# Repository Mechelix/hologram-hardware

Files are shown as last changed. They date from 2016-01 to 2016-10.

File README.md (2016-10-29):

# Hologram Dash and Dash Pro Hardware Repo

Welcome to Hologram
We hope you enjoy using our hardware

This is the repo for the Dash and Dash Pro

You can find everything you need to at
https://hologram.io/start

You can find the user manual here:
https://hologram.io/docs/hardware/hologram-dash/

There is also a great index of documentation here:
https://hologram.io/docs/

You can find our forums here. We really want to hear about your projects!
https://community.hologram.io/

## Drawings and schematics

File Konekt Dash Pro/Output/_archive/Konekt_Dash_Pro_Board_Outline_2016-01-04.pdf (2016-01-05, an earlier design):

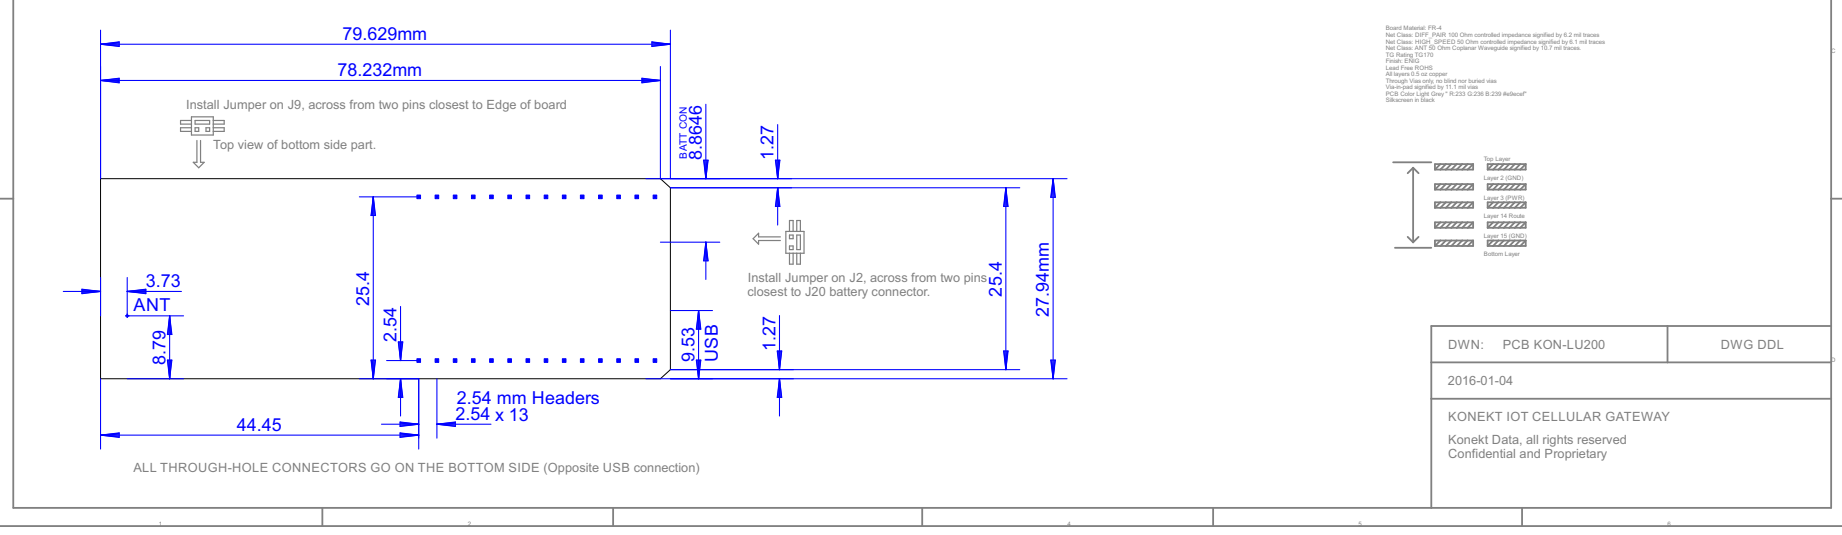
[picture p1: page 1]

Board Material: FR-4 Net Class: DIFF_PAIR 100 Ohm controlled impedance signified by 6.2 mil traces Net Class: HIGH_SPEED 50 Ohm controlled impedance signified by 6.1 mil traces Net Class: ANT 50 Ohm Coplanar Waveguide signified by 10.7 mil traces. TG Rating TG170 Finish: ENIG

Lead Free ROHS
All layers 0.5 oz copper Through Vias only, no blind nor buried vias Via-in-pad signified by 11.1 mil vias PCB Color Light Grey " R:233 G:236 B:239 #e9ecef" Silkscreen in black

Install Jumper on J9, across from two pins closest to Edge of board Top view of bottom side part.

Top Layer Layer 2 (GND) Layer 3 (PWR) Layer 14 Route

Layer 15 (GND) Bottom Layer

Install Jumper on J2, across from two pins
closest to J20 battery connector.

DWN: 2016-01-04 KONEKT IOT CELLULAR GATEWAY

Konekt Data, all rights reserved Confidential and Proprietary

ALL THROUGH-HOLE CONNECTORS GO ON THE BOTTOM SIDE (Opposite USB connection)

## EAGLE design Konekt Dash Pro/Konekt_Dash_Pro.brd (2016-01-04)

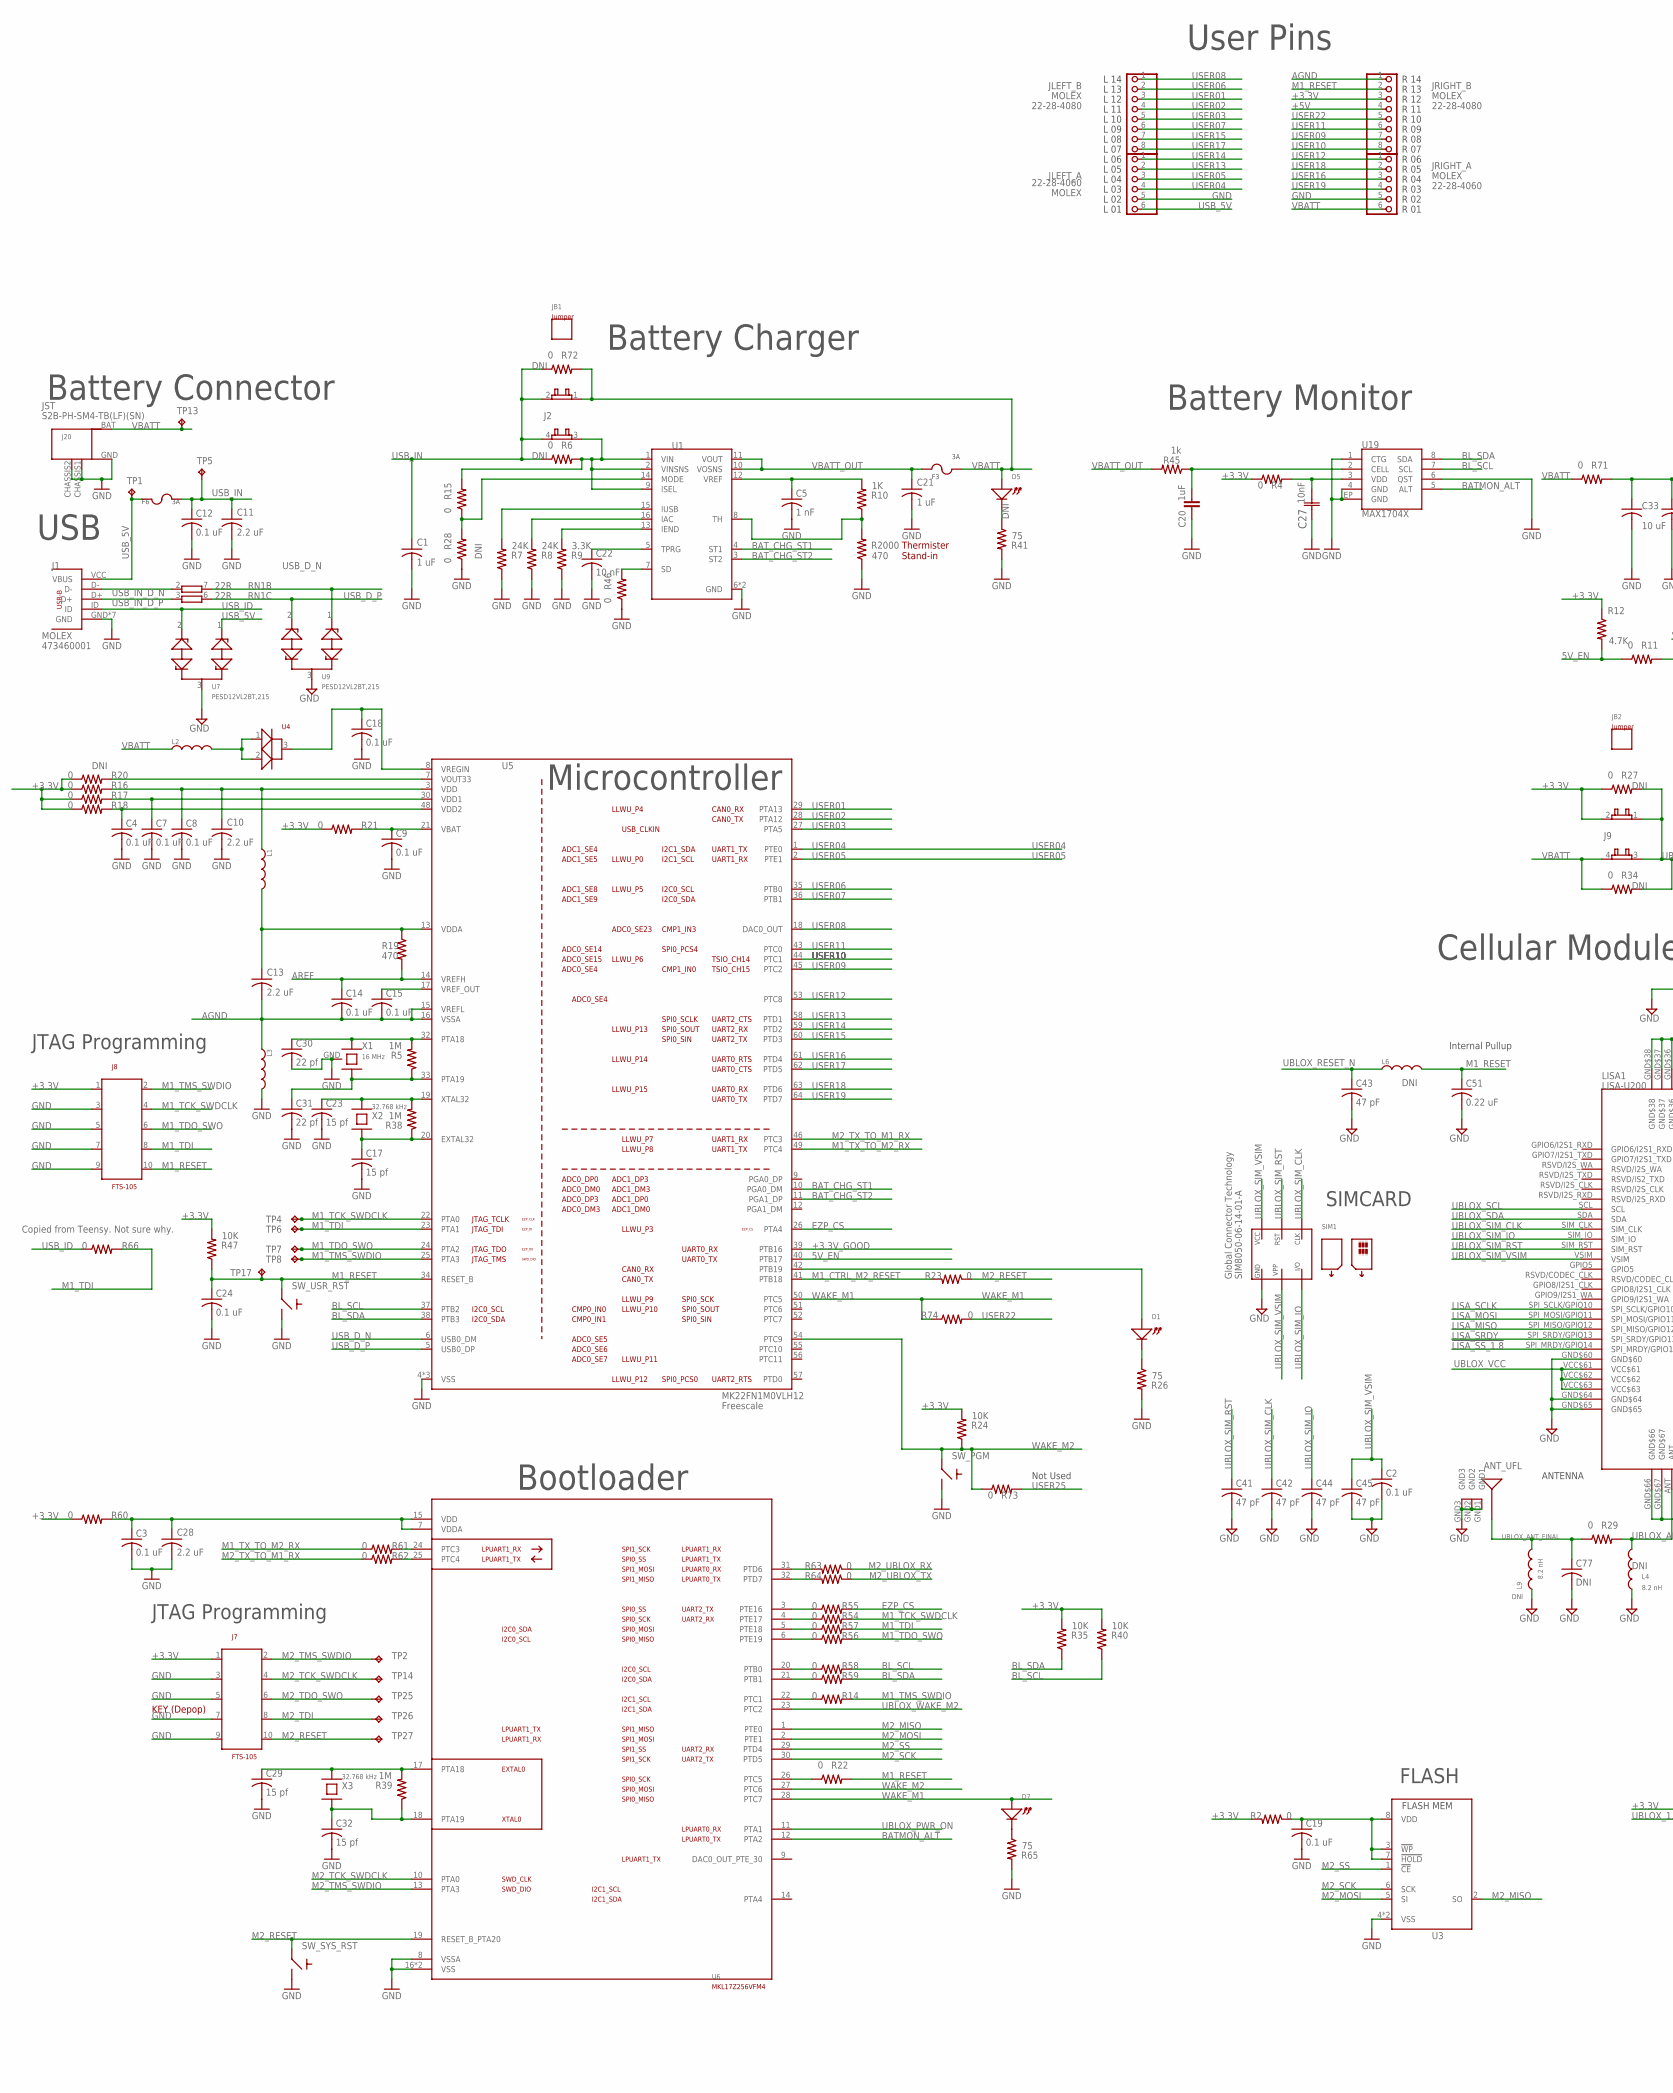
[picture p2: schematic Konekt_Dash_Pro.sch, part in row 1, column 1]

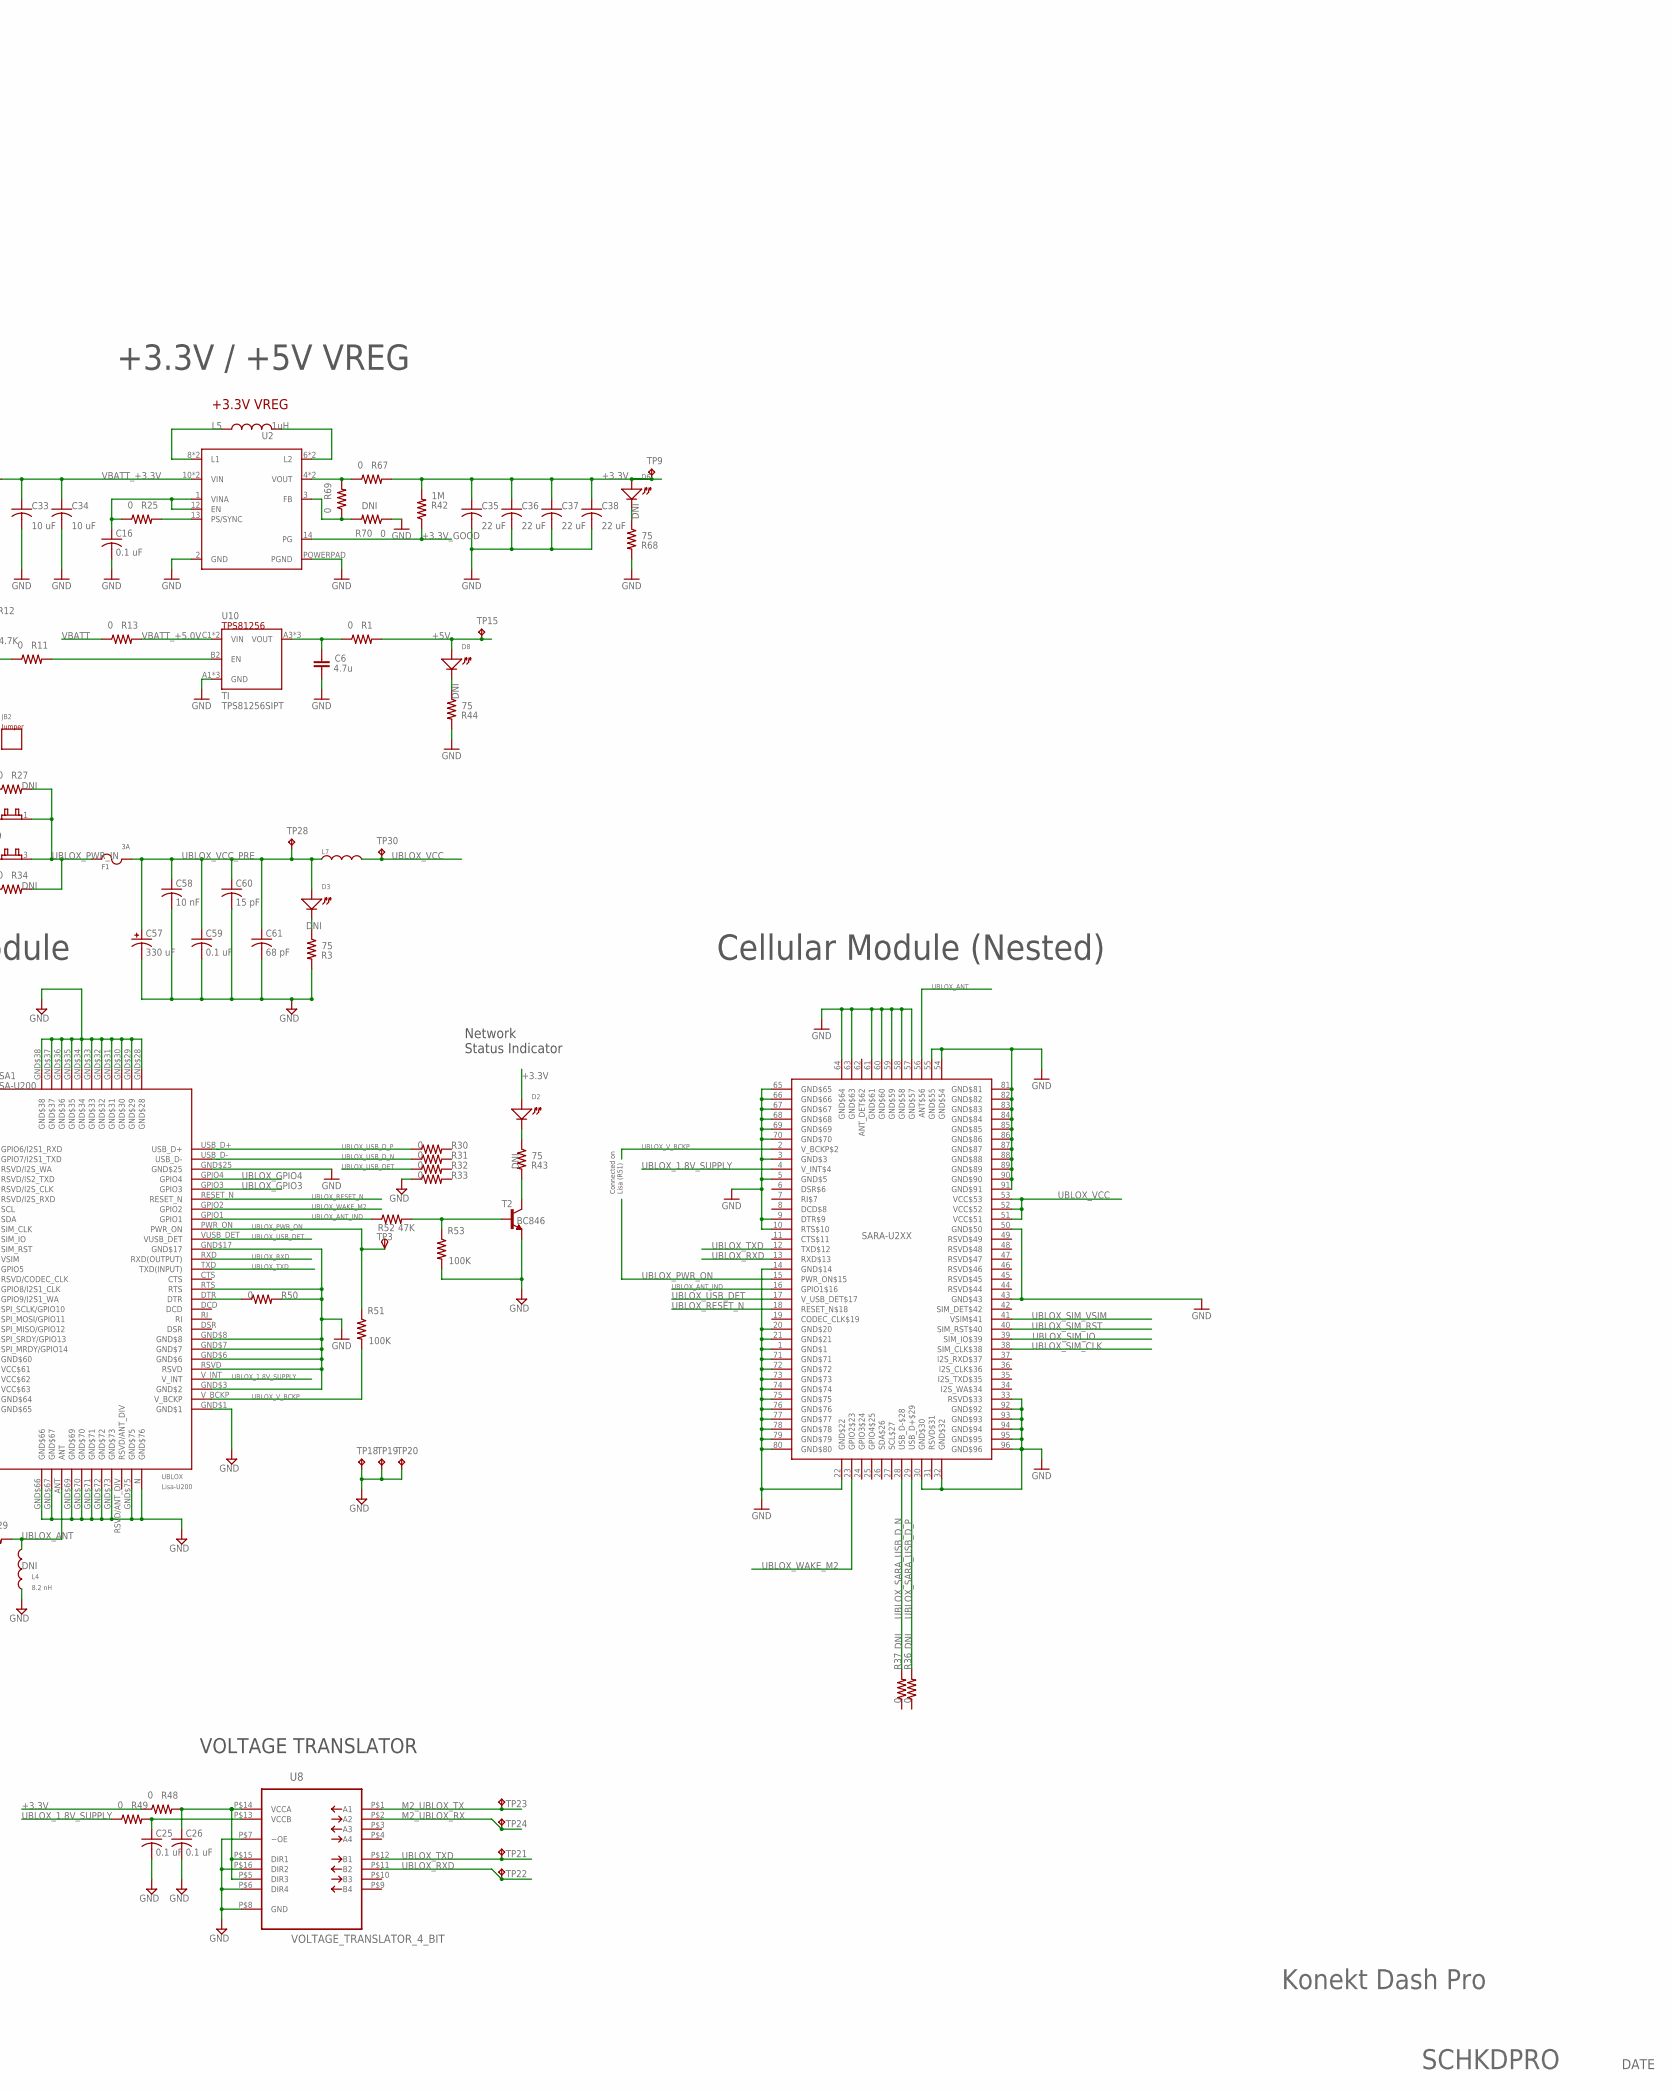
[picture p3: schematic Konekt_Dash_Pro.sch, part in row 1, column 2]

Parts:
ANT_UFL: ANT-A-1JB; UFL; MPN A-1JB
C1, C21: 1 uF; C0603; MPN GRM188R71C105KA12D
C2, C3, C4, C7, C8, C9, C14, C15, C18, C19, C24, C25, C26: 0.1 uF; C0402; MPN GRM155R61C104KA88D
C5: 1 nF; C0402; MPN GRM319R71H102KA01D
C6: 4.7u; C0603-ROUND; MPN GRM188R61C475KAAJD
C10, C11, C13, C28: 2.2 uF; C0603; MPN CL10A225MQ8NNNC
C12, C16, C59: 0.1 uF; C0603; MPN 0603YC104KAT2A
C17, C23, C29, C32: 15 pf; C0402; MPN 04025A150JAT2A
C20: 1uF; 0402-CAP; TOLERANCE 10%; VOLTAGE 50V; MPN 04026D105KAT2A
C22, C58: 10 nF; C0402; MPN GRM155R71C103KA01D
C27: 10nF; CAPC1005X60N
C30, C31: 22 pf; C0402; MPN 04025A220JAT2A
C33, C34: 10 uF; C0603; MPN GRM188R60J106ME84D
C35, C36, C37, C38: 22 uF; C0603; MPN GRM188R60J226MEA0D
C41, C42, C43, C44, C45: 47 pF; C0402; MPN 04025A470JAT2A
C51: 0.22 uF; C0603; MPN 0603YC224KAT2A
C57: 330 uF; CAP_SMD_SIZE_D; MPN T520D337M006ATE045
C60: 15 pF; C0402; MPN NMC0402NPO150J50TRPF
C61: 68 pF; C0402; MPN GRM1555C1H680JA01D
C77: DNI; C0402; MPN DNI
D1, D2, D3, D5, D6, D7, D8: LED_0402_VLMW; LED_0402_VISHAY_VLMW
F1, F3, F6: 3A; R0603; MPN SF-0603S300-2
J1: USB_MICRO_B_MOLEX_473460001; USB_MICRO_MOLEX_473460001; MPN 473460001
J2, J9: CON_JUMPER_1.27_2X2; FCI_CON_1.27_2X2
J7, J8: FTS-105; MPN FTS-105-01-F-DV
J20: BAT_TERM; JST-PH-2; MPN S2B-PH-SM4-TB(LF)(SN)
JB1, JB2: JUMPER_1.27MM; NOTHING
JLEFT_A: PINHD-1X6; 1X06; MPN 22-28-4060
JLEFT_B: HEADER_0.1_IN_8_POS; HEADER_0.1_8_POS; MPN 22-28-4080
JRIGHT_A: PINHD-1X6; 1X06; MPN 22-28-4060
JRIGHT_B: HEADER_0.1_IN_8_POS; HEADER_0.1_8_POS; MPN 22-28-4080
L1, L3: INDUCTOR_0603; R0603$1; MPN BLM18AG121SN1D
L2: INDUCTOR_0603; R0603$1; MPN MPZ1608S221A
L4, L9: INDUCTOR_0402; R0402; MPN DNI
L5: 1uH; COILCRAFT_XFL4020
L6: INDUCTOR_0603; R0603$1; MPN DNI
L7: INDUCTOR_0603; R0603$1; MPN BLM18EG221SN1D
LISA1: LISA-U200; 76PIN_LCC; MPN LISA-U200-02S
R1, R2, R4, R11, R13, R14, R15, R16, R17, R18, R21, R22, R23, R25, R29, R30, R31, R32, R33, R46, R48, R49, R50, R54, R55, R56, R57, R58, R59, R60, R61, R62, R63, R64, R66, R67, R69, R71, R73, R74: 0; 0402-RES; MPN ERJ-2GE0R00X
R3, R41, R43, R44, R68: 75; 0402-RES; MPN DNI
R5, R38, R39, R42: 1M; 0402-RES; MPN RC0402JR-071ML
R6, R20, R27, R28, R34, R36, R37, R70, R72: 0; 0402-RES; MPN DNI
R7, R8: 24K; 0402-RES; MPN RC0402JR-0724KL
R9: 3.3K; 0402-RES; MPN RC0402JR-073K3L
R10: 1K; 0402-RES; MPN RC0402JR-071KL
R12: 4.7K; R0402; MPN ERJ-2GEJ472X
R19: 470; R0402; MPN ERJ-2GEJ471X
R24, R35, R40, R47: 10K; 0402-RES; MPN RC0402JR-0710KL
R26, R65: 75; 0402-RES; MPN ERJ-2GEJ750X
R45: 1k; 0402-RES; TOLERANCE 5%; MPN RC0402JR-071KL
R51, R53: 100K; R0402; MPN ERJ-2GEJ104X
R52: 47K; R0402; MPN ERJ-2GEJ473X
R2000: 470; 0402-RES; MPN RC0402JR-07470RL
RN1: 22R; CAY16; MPN CAY16-220J4LF
SARA1: SARA-U2XX; 91-PIN_LGA; MPN DNI
SIM1: SIM_CARD_NANO_GLOBAL_CONNECTOR_TEC_SIM8050-6-0-14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; SIM_CARD_NANO
SW_PGM: SWITCH_PANASONIC_EVP-BB2A1B000; SWITCH_PANASONIC_EVPBB
SW_SYS_RST: SWITCH_PANASONIC_EVP-BB2A1B000; SWITCH_PANASONIC_EVPBB
SW_USR_RST: SWITCH_PANASONIC_EVP-BB2A1B000; SWITCH_PANASONIC_EVPBB
T2: BC846; SOT23; MPN BC846ALT1G
TP1, TP2, TP4, TP5, TP6, TP7, TP8, TP9, TP13, TP14, TP15, TP17, TP18, TP19, TP20, TP21, TP22, TP23, TP24, TP25, TP26, TP27, TP28, TP30: TPTP08R; TP08R; MPN N/A
TP3: TPSTP09R; TP09R; MPN N/A
U1: ST_MICRO_BAT_CHARGER_L6924U013; BAT_CHARGE_ST_MICRO_L6924U; MPN L6924UTR
U2: TPS63021; QFN-14-POWERPAD3X4DSJ; MPN TPS63021DSJR
U3: MICROCHIP_FLASH_MEM; TDFN8_5X6; MPN SST26VF016BT-104I/MF
U4: DIODE_DUAL_SCHOTKEY; SOT23-3; MPN_DNI BAT54C
U5: MK20DX128VLH5; MPN MK22FN1M0VLH12
U6: FREESCALE_MKL17Z256VFM4; QFN_32_5X5
U7, U9: PESD12VL2BT,215; SOT23; MPN PESD12VL2BT,215
U8: VOLTAGE_TRANSLATOR_4_BIT; UQFN_16
U10: BOOST_5V_TI_TPS81256; MICRO_SIP_3X3
U19: MAX1704X; TDFN-8; MPN MAX17043G+U
X1: 16 MHz; CRYSTAL_RESONATOR_MURATA_CSTCE
X2, X3: 32.768 kHz; CRYSTAL_ST3215SB

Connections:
5V_EN: R11.1, R12.2, U5.40 (PTB17)
!LISA_SS_1.8: LISA1.SPI_MRDY/GPIO14
+3.3V: C35.1, C36.1, C37.1, C38.1, D2.ANODE, D6.ANODE, J7.1, J8.1, J9.2, JRIGHT_B.3, R2.2, R4.1, R12.1, R16.1, R17.1, R18.1, R20.1, R21.1, R24.2, R27.1, R35.2, R40.2, R42.2, R47.2, R48.1, R60.1, R67.2, TP9.TP
+3.3V_FLASH: C19.1, R2.1, U3.3 (!WP), U3.7 (!HOLD), U3.8 (VDD)
+3.3V_GOOD: R42.1, U2.14 (PG), U5.39 (PTB16)
+5V: D8.ANODE, JRIGHT_B.4, R1.2, TP15.TP
AGND: C13.2, C14.2, C15.2, JRIGHT_B.1, L3.1, U5.15 (VREFL), U5.16 (VSSA)
ANT_DET$62: SARA1.62 (ANT_DET$62)
AREF: C14.1, R19.2, U5.14 (VREFH)
BATMON_ALT: U6.12 (PTA2), U19.5 (ALT)
BAT_CHG_ST1: U1.4 (ST1), U5.10 (PGA0_DM)
BAT_CHG_ST2: U1.3 (ST2), U5.11 (PGA1_DP)
BL_SCL: R40.1, R58.2, U5.37 (PTB2), U19.7 (SCL)
BL_SDA: R35.1, R59.2, U5.38 (PTB3), U19.8 (SDA)
EZP_CS: R55.2, U5.26 (PTA4)
GND: ANT_UFL.GND1, ANT_UFL.GND2, ANT_UFL.GND3, C1.2, C2.2, C3.2, C4.2, C5.2, C6.1, C7.2, C8.2, C9.2, C10.2, C11.2, C12.2, C16.2, C17.2, C18.2, C19.2, C20.2, C21.2, C22.2, C23.2, C24.2, C25.2, C26.2, C27.1 (C1), C28.2, C29.2, C30.2, C31.2, C32.2, C33.2, C34.2, C35.2, C36.2, C37.2, C38.2, C41.2, C42.2, C43.2, C44.2, C45.2, C51.2, C57.P$2 (NEG), C58.2, C59.2, C60.2, C61.2, C77.2, J1.GND, J1.GND$1 (GND), J1.GND$2 (GND), J1.GND$3 (GND), J1.GND$4 (GND), J1.GND$5 (GND), J1.GND$6 (GND), J7.3, J7.5, J7.7, J7.9, J8.3, J8.5, J8.7, J8.9, J20.CHASSIS1 (CHASSIS_1), J20.CHASSIS2 (CHASSIS_2), J20.GND, JLEFT_A.5, JRIGHT_A.5, L3.2, L4.2, L9.2, LISA1.GND$1, LISA1.GND$3 (GND$2), LISA1.GND$6, LISA1.GND$7, LISA1.GND$8, LISA1.GND$17, LISA1.GND$25, LISA1.GND$28, LISA1.GND$29, LISA1.GND$30, LISA1.GND$31, LISA1.GND$32, LISA1.GND$33, LISA1.GND$34, LISA1.GND$35, LISA1.GND$36, LISA1.GND$37, LISA1.GND$38, LISA1.GND$60, LISA1.GND$64, LISA1.GND$65, LISA1.GND$66, LISA1.GND$67, LISA1.GND$69, LISA1.GND$70, LISA1.GND$71, LISA1.GND$72, LISA1.GND$73, LISA1.GND$75, LISA1.N (GND$76), LISA1.RSVD, LISA1.RTS, R3.2, R7.1, R8.1, R9.1, R26.2, R28.1, R33.1, R41.2, R44.2, R46.1, R50.2, R53.2, R65.2, R68.2, R70.1, R2000.1, SARA1.1 (GND$1), SARA1.3 (GND$3), SARA1.5 (GND$5), SARA1.9 (DTR$9), SARA1.10 (RTS$10), SARA1.14 (GND$14), SARA1.20 (GND$20), SARA1.21 (GND$21), SARA1.22 (GND$22), SARA1.30 (GND$30), SARA1.32 (GND$32), SARA1.33 (RSVD$33), SARA1.43 (GND$43), SARA1.50 (GND$50), SARA1.54 (GND$54), SARA1.55 (GND$55), SARA1.57 (GND$57), SARA1.58 (GND$58), SARA1.59 (GND$59), SARA1.60 (GND$60), SARA1.61 (GND$61), SARA1.63 (GND$63), SARA1.64 (GND$64), SARA1.65 (GND$65), SARA1.66 (GND$66), SARA1.67 (GND$67), SARA1.68 (GND$68), SARA1.69 (GND$69), SARA1.70 (GND$70), SARA1.71 (GND$71), SARA1.72 (GND$72), SARA1.73 (GND$73), SARA1.74 (GND$74), SARA1.75 (GND$75), SARA1.76 (GND$76), SARA1.77 (GND$77), SARA1.78 (GND$78), SARA1.79 (GND$79), SARA1.80 (GND$80), SARA1.81 (GND$81), SARA1.82 (GND$82), SARA1.83 (GND$83), SARA1.84 (GND$84), SARA1.85 (GND$85), SARA1.86 (GND$86), SARA1.87 (GND$87), SARA1.88 (GND$88), SARA1.89 (GND$89), SARA1.90 (GND$90), SARA1.91 (GND$91), SARA1.92 (GND$92), SARA1.93 (GND$93), SARA1.94 (GND$94), SARA1.95 (GND$95), SARA1.96 (GND$96), SIM1.C5-GND (GND), SW_PGM.B, SW_PGM.B2, SW_SYS_RST.B, SW_SYS_RST.B2, SW_USR_RST.B, SW_USR_RST.B2, T2.2 (E), TP18.TP, TP19.TP, TP20.TP, U1.6 (GND), U1.PAD (GND), U2.2 (GND), U2.POWERPAD (PGND), U3.4 (VSS), U3.P$9 (VSS), U5.4 (VSS), U5.31 (VSS), U5.47 (VSS), U6.8 (VSSA), U6.16 (VSS), U6.PAD (VSS), U7.3, U8.P$6 (DIR4), U8.P$7 (~OE), U8.P$8 (GND), U8.P$16 (DIR2), U9.3, U10.A1 (GND), U10.A2 (GND), U10.B1 (GND), U19.1 (CTG), U19.4 (GND), U19.6 (QST), U19.EP (GND), X1.GND
GPIO4$25: SARA1.25 (GPIO4$25)
I2S_TXD$35: SARA1.35 (I2S_TXD$35)
I2S_WA$34: SARA1.34 (I2S_WA$34)
LISA_MISO: LISA1.SPI_MISO/GPIO12
LISA_MOSI: LISA1.SPI_MOSI/GPIO11
LISA_SCLK: LISA1.SPI_SCLK/GPIO10
LISA_SRDY: LISA1.SPI_SRDY/GPIO13
M1_CTRL_M2_RESET: R23.2, U5.41 (PTB18)
M1_RESET: C24.1, C51.1, J8.10, JRIGHT_B.2, L6.2, R22.2, R47.1, SW_USR_RST.A, SW_USR_RST.A2, TP17.TP, U5.34 (RESET_B)
M1_TCK_SWDCLK: J8.4, R54.2, TP4.TP, U5.22 (PTA0)
M1_TDI: J8.8, R57.2, R66.2, TP6.TP, U5.23 (PTA1)
M1_TDO_SWO: J8.6, R56.2, TP7.TP, U5.24 (PTA2)
M1_TMS_SWDIO: J8.2, R14.2, TP8.TP, U5.25 (PTA3)
M1_TX_TO_M2_RX: R61.1, U5.49 (PTC4)
M2_MISO: U3.2 (SO), U6.1 (PTE0)
M2_MOSI: U3.5 (SI), U6.2 (PTE1)
M2_RESET: J7.10, R23.1, SW_SYS_RST.A, SW_SYS_RST.A2, TP27.TP, U6.19 (RESET_B_PTA20)
M2_RX: R61.2, U6.24 (PTC3)
M2_SCK: U3.6 (SCK), U6.30 (PTD5)
M2_SPI0_MISO: R56.1, U6.6 (PTE19)
M2_SPI0_MOSI: R57.1, U6.5 (PTE18)
M2_SS: U3.1 (!CE), U6.29 (PTD4)
M2_TCK_SWDCLK: J7.4, TP14.TP, U6.10 (PTA0)
M2_TDI: J7.8, TP26.TP
M2_TDO_SWO: J7.6, TP25.TP
M2_TMS_SWDIO: J7.2, TP2.TP, U6.13 (PTA3)
M2_TX: R62.2, U6.25 (PTC4)
M2_TX_TO_M1_RX: R62.1, U5.46 (PTC3)
M2_UBLOX_RX: R63.1, TP24.TP, U8.P$2 (A2)
M2_UBLOX_TX: R64.1, TP23.TP, U8.P$1 (A1)
unnamed: C20.1, R45.1, U19.2 (CELL)
unnamed: D1.ANODE, U5.42 (PTB19)
unnamed: C27.2 (C2), R4.2, U19.3 (VDD)
unnamed: J2.3, R6.2, R15.2, U1.1 (VIN), U1.2 (VINSNS), U1.9 (ISEL)
unnamed: R10.1, R2000.2, U1.8 (TH)
unnamed: C5.1, R10.2, U1.12 (VREF)
unnamed: D3.CATHODE, R3.1
unnamed: R7.2, U1.15 (IUSB)
unnamed: L5.P$1, U2.8 (L1), U2.9 (L1)
unnamed: R8.2, U1.16 (IAC)
unnamed: C30.1, R5.2, U5.32 (PTA18), X1.XTAL1
unnamed: R9.2, U1.13 (IEND)
unnamed: D5.CATHODE, R41.1
unnamed: C22.1, U1.5 (TPRG)
unnamed: C6.2, R1.1, U10.A3 (VOUT), U10.B3 (VOUT), U10.C3 (VOUT)
unnamed: R11.2, U10.B2 (EN)
unnamed: C8.1, C10.1, L1.1, R16.2, U5.3 (VDD)
unnamed: C7.1, R17.2, U5.30 (VDD1)
unnamed: C4.1, R18.2, U5.48 (VDD2)
unnamed: C18.1, U4.3 (C), U5.8 (VREGIN)
unnamed: R20.2, U5.7 (VOUT33)
unnamed: C15.1, U5.17 (VREF_OUT)
unnamed: C13.1, L1.2, R19.1, U5.13 (VDDA)
unnamed: D8.CATHODE, R44.1
unnamed: L2.2, U4.1 (A1), U4.2 (A2)
unnamed: LISA1.DTR, R50.1
unnamed: C9.1, R21.2, U5.21 (VBAT)
unnamed: C31.1, R5.1, U5.33 (PTA19), X1.XTAL2
unnamed: C23.1, R38.2, U5.19 (XTAL32), X2.P$2 (XTAL2)
unnamed: R58.1, U6.20 (PTB0)
unnamed: C17.1, R38.1, U5.20 (EXTAL32), X2.P$1 (XTAL1)
unnamed: L5.P$2, U2.6 (L2), U2.7 (L2)
unnamed: D1.CATHODE, R26.1
unnamed: C16.1, R25.1, U2.1 (VINA), U2.12 (EN)
unnamed: R14.1, U6.22 (PTC1)
unnamed: R15.1, R28.2, U1.14 (MODE)
unnamed: R46.2, U1.7 (SD)
unnamed: R67.1, R69.2, U2.4 (VOUT), U2.5 (VOUT)
unnamed: R63.2, U6.31 (PTD6)
unnamed: R64.2, U6.32 (PTD7)
unnamed: R55.1, U6.3 (PTE16)
unnamed: R54.1, U6.4 (PTE17)
unnamed: R59.1, U6.21 (PTB1)
unnamed: R22.1, U6.26 (PTC5)
unnamed: C3.1, C28.1, R60.2, U6.7 (VDDA), U6.15 (VDD)
unnamed: D7.CATHODE, R65.1
unnamed: C32.1, R39.1, U6.18 (PTA19), X3.P$1 (XTAL1)
unnamed: C29.1, R39.2, U6.17 (PTA18), X3.P$2 (XTAL2)
unnamed: R25.2, U2.13 (PS/SYNC)
unnamed: D6.CATHODE, R68.1
unnamed: R69.1, R70.2, U2.3 (FB)
unnamed: D2.CATHODE, R43.1
unnamed: R52.2, R53.1, T2.1 (B)
unnamed: R43.2, T2.3 (C)
RSVD$31: SARA1.31 (RSVD$31)
SCL$27: SARA1.27 (SCL$27)
SDA$26: SARA1.26 (SDA$26)
UBLOX_1.8V_SUPPLY: LISA1.V_INT, R49.1, SARA1.4 (V_INT$4)
UBLOX_ANT: L4.1, LISA1.ANT, R29.2, SARA1.56 (ANT$56)
UBLOX_ANT_FINAL: ANT_UFL.SIGNAL, C77.1, L9.1, R29.1
UBLOX_ANT_IND: LISA1.GPIO1, R52.1, SARA1.16 (GPIO1$16)
UBLOX_GPIO3: LISA1.GPIO3
UBLOX_GPIO4: LISA1.GPIO4
UBLOX_PWR_IN: F1.2, J9.1, J9.3, R27.2, R34.2
UBLOX_PWR_ON: LISA1.PWR_ON, R51.1, SARA1.15 (PWR_ON$15), TP3.TP, U6.11 (PTA1)
UBLOX_RESET_N: C43.1, L6.1, LISA1.RESET_N, SARA1.18 (RESET_N$18)
UBLOX_RXD: LISA1.RXD (RXD(OUTPUT)), SARA1.13 (RXD$13), TP22.TP, U8.P$11 (B2)
UBLOX_SARA_USB_D_N: R37.2, SARA1.28 (USB_D-$28)
UBLOX_SARA_USB_D_P: R36.2, SARA1.29 (USB_D+$29)
UBLOX_SCL: LISA1.SCL
UBLOX_SDA: LISA1.SDA
UBLOX_SIM_CLK: C42.1, LISA1.SIM_CLK, SARA1.38 (SIM_CLK$38), SIM1.C3-CLK (CLK)
UBLOX_SIM_IO: C44.1, LISA1.SIM_IO, SARA1.39 (SIM_IO$39), SIM1.C7-IO (IO)
UBLOX_SIM_RST: C41.1, LISA1.SIM_RST, SARA1.40 (SIM_RST$40), SIM1.C2-RST (RST)
UBLOX_SIM_VSIM: C2.1, C45.1, LISA1.VSIM, SARA1.41 (VSIM$41), SIM1.C1-VCC (VCC), SIM1.C6-VPP (VCC2)
UBLOX_TXD: LISA1.TXD (TXD(INPUT)), SARA1.12 (TXD$12), TP21.TP, U8.P$12 (B1)
UBLOX_USB_DET: LISA1.VUSB_DET, R32.1, SARA1.17 (V_USB_DET$17)
UBLOX_USB_D_N: LISA1.USB_D-, R31.1
UBLOX_USB_D_P: LISA1.USB_D+, R30.1
UBLOX_VCC: L7.2, LISA1.VCC$61, LISA1.VCC$62, LISA1.VCC$63, SARA1.51 (VCC$51), SARA1.52 (VCC$52), SARA1.53 (VCC$53), TP30.TP
UBLOX_VCC_PRE: C57.P$1 (POS), C58.1, C59.1, C60.1, C61.1, D3.ANODE, F1.1, L7.1, TP28.TP
UBLOX_V_BCKP: LISA1.V_BCKP, R51.2, SARA1.2 (V_BCKP$2)
UBLOX_WAKE_M2: LISA1.GPIO2, SARA1.23 (GPIO2$23), U6.23 (PTC2)
USB_5V: F6.1, J1.VCC (VBUS), JLEFT_A.6, TP1.TP, U7.1
USB_D_N: RN1.7 (2), U5.6 (USB0_DM), U9.1
USB_D_P: RN1.6 (2), U5.5 (USB0_DP), U9.2
USB_ID: J1.ID, R66.1, U7.2
USB_IN: C1.1, C11.1, C12.1, F6.2, J2.2, J2.4, R6.1, R72.1, TP5.TP
USB_IN_D_N: J1.D-, RN1.2 (1)
USB_IN_D_P: J1.D+, RN1.3 (1)
USER01: JLEFT_B.3, U5.29 (PTA13)
USER02: JLEFT_B.4, U5.28 (PTA12)
USER03: JLEFT_B.5, U5.27 (PTA5)
USER04: JLEFT_A.4, U5.1 (PTE0)
USER05: JLEFT_A.3, U5.2 (PTE1)
USER06: JLEFT_B.2, U5.35 (PTB0)
USER07: JLEFT_B.6, U5.36 (PTB1)
USER08: JLEFT_B.1, U5.18 (DAC0_OUT)
USER09: JRIGHT_B.7, U5.45 (PTC2)
USER10: JRIGHT_B.8, U5.44 (PTC1)
USER11: JRIGHT_B.6, U5.43 (PTC0)
USER12: JRIGHT_A.1, U5.53 (PTC8)
USER13: JLEFT_A.2, U5.58 (PTD1)
USER14: JLEFT_A.1, U5.59 (PTD2)
USER15: JLEFT_B.7, U5.60 (PTD3)
USER16: JRIGHT_A.3, U5.61 (PTD4)
USER17: JLEFT_B.8, U5.62 (PTD5)
USER18: JRIGHT_A.2, U5.63 (PTD6)
USER19: JRIGHT_A.4, U5.64 (PTD7)
USER22: JRIGHT_B.5, R74.2
USER25: R73.2
VBATT: D5.ANODE, F3.1, J2.1, J9.4, J20.BAT, JRIGHT_A.6, L2.1, R13.1, R34.1, R71.1, R72.2, TP13.TP
VBATT_+3.3V: C33.1, C34.1, R71.2, U2.10 (VIN), U2.11 (VIN)
VBATT_+5.0V: R13.2, U10.C1 (VIN), U10.C2 (VIN)
VBATT_OUT: C21.1, F3.2, R45.2, U1.10 (VOSNS), U1.11 (VOUT)
VTL_+3.3V1: C26.1, R48.2, U8.P$5 (DIR3), U8.P$14 (VCCA), U8.P$15 (DIR1)
VTL_LISA_VCC1: C25.1, R49.2, U8.P$13 (VCCB)
WAKE_M1: D7.ANODE, R74.1, U5.50 (PTC5), U6.28 (PTC7)
WAKE_M2: R24.1, R73.1, SW_PGM.A, SW_PGM.A2, U5.54 (PTC9), U6.27 (PTC6)

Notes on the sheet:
Network Status Indicator
SIMCARD
LISA1
Microcontroller
Thermister Stand-in
User Pins
Bootloader
Battery Connector
USB
Battery Charger
Battery Monitor
+3.3V / +5V VREG
ANTENNA
VOLTAGE TRANSLATOR
+3.3V VREG
EZP_CLK
EZP_DI
EZP_D0
SWD_DIO
EZP_CS
JTAG Programming
KEY (Depop)
Copied from Teensy. Not sure why.
Cellular Module (Nested)
Konekt Dash Pro
DATE
SCHKDPRO
Cellular Module
FLASH
Connected on Lisa (R51)
R 01
R 02
R 03
R 04
R 05
R 06
R 07
R 08
R 09
R 10

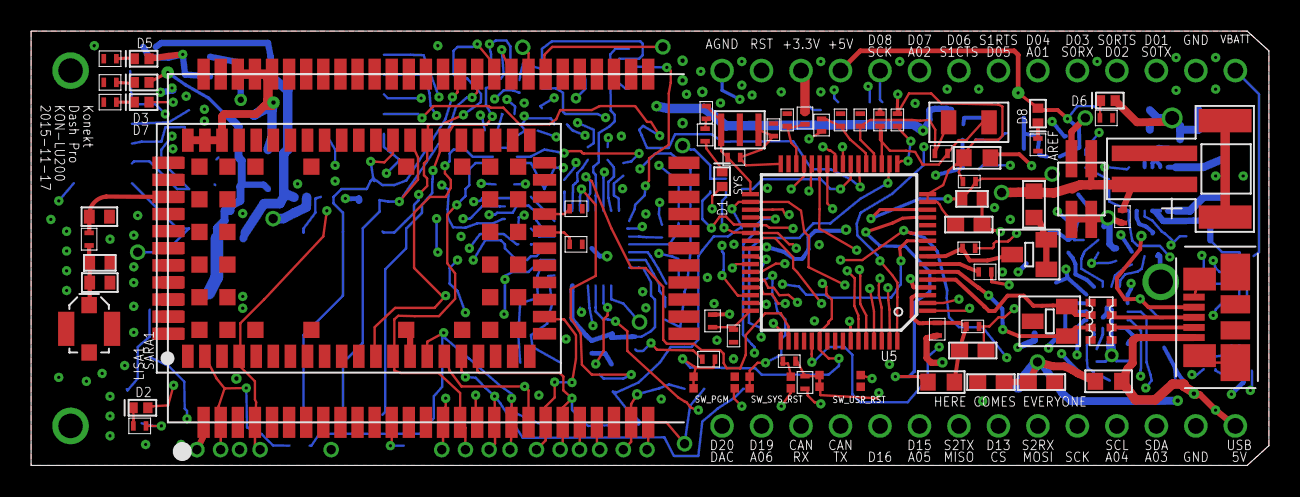
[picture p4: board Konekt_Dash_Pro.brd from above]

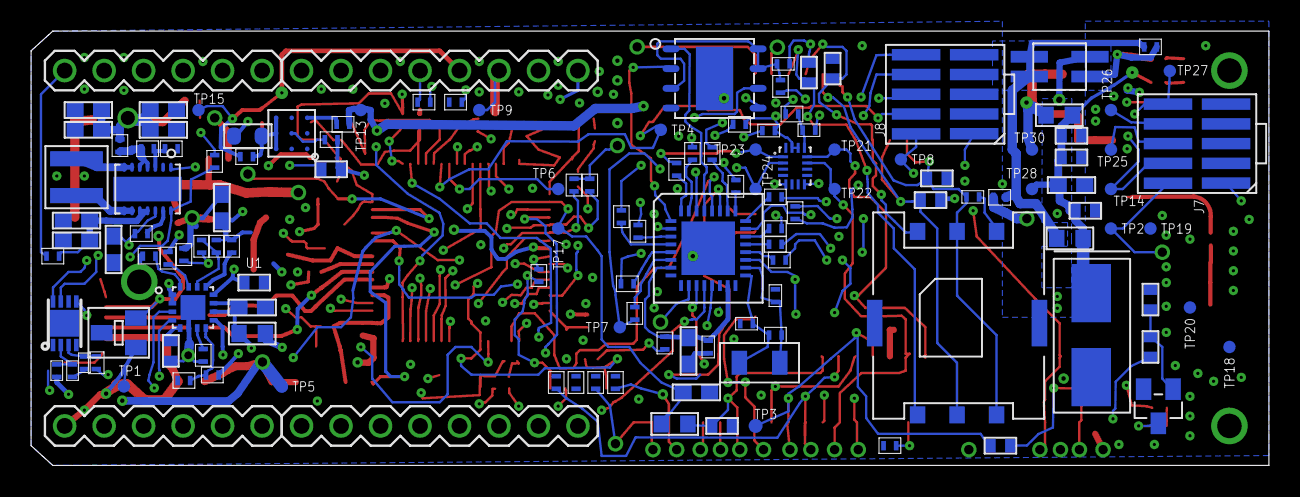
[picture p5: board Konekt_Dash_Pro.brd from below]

Board: 6 copper layers, 79.6 x 27.9 mm, 203 parts (135 on the bottom side), 148 nets.

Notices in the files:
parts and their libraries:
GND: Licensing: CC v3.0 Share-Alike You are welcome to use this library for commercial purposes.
